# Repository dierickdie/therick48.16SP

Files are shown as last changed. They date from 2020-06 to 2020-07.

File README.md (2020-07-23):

# therick48.16SP
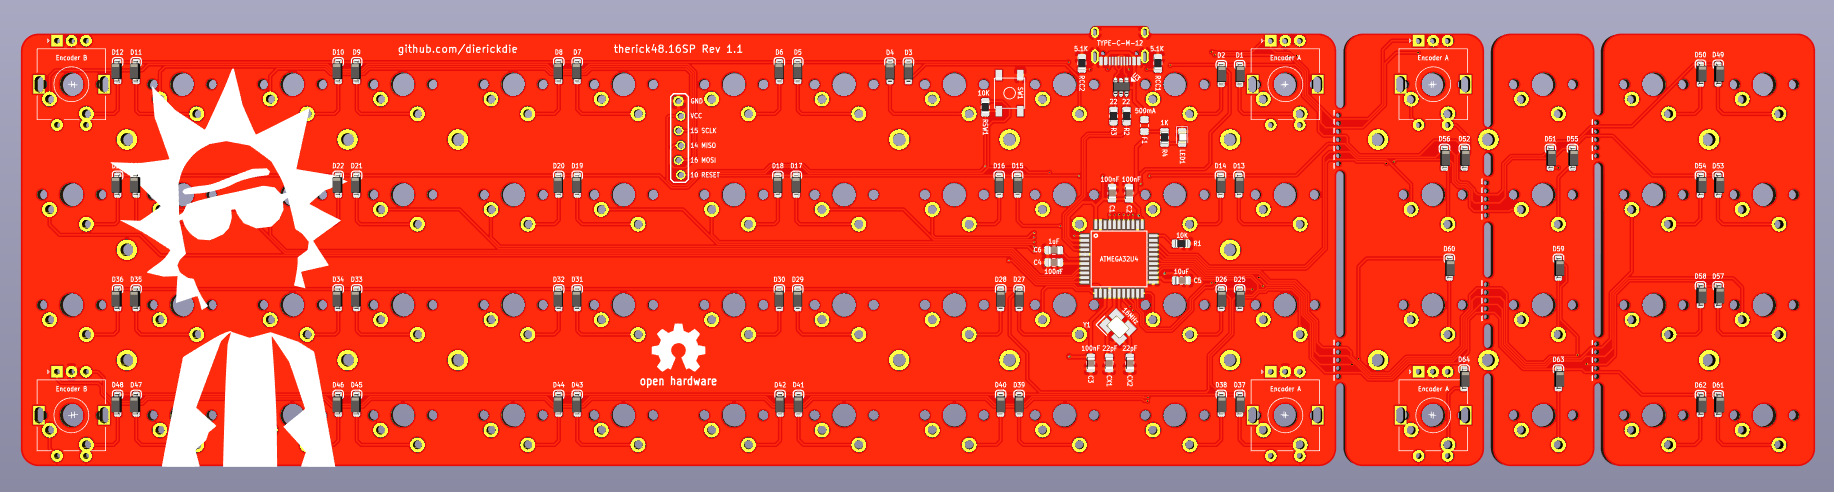
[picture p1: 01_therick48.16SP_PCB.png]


SP = Southpaw

A 4x12 + 4x4 (48.16) ortho keyboard with USB C, SMD components, and 19mm spacing.

This is essentially a dumbed down Planck clone plus a southpaw numpad. The numpad is able to be snapped off to have just a 4x12.

If you want a regular side numpad, look at the [therick48.16](https://github.com/dierickdie/therick64BA). It uses the same firmware.

**Note: firmware is the same as therick48.16**

Although everything should<sup>(tm)</sup> work as is, it hasn't been physically tested.

**USE AT YOUR OWN RISK!!!** I am not responsible for any dumb things you do, fry your computer, break anything, etc.

## FAQ:
#### Does it have MIT/2x2u/etc.? 
No. Grid for life

#### Does it have backlighting?
No

#### Does it have RGB?
No

#### Does it have a rotary encoder?
~No~ Yep! There are 8 (lol) choices for location. However, only support for 2. Left and right.

#### Does it have hotswap?
No

#### Does it have Alps support?
No

#### Choc support?
No

#### Will you add any of these?
No

#### Why not?
I don't wanna

#### Will it fit a Planck case?
Yes! In theory. If you break off the numpad. Hasn't been tested.

#### Why USB C?
That's a dumb question

#### Will you add micro/mini/any USB other than type C?
No

#### Why not?
USB C is the future. Until a new standard comes out

#### But I don't have any USB C cables.
Boo hoo. I suggest building one. Zap Cables is a good place to get parts

#### Why is it named therick?
It started in fall of 2005 when I was just a boy. I started a new job, and needed a login name. The manager wrote The Rick (my first name is Rick). It has stuck ever since. Thanks, Sam! 64 is for 64 keys. Hope that was obvious.

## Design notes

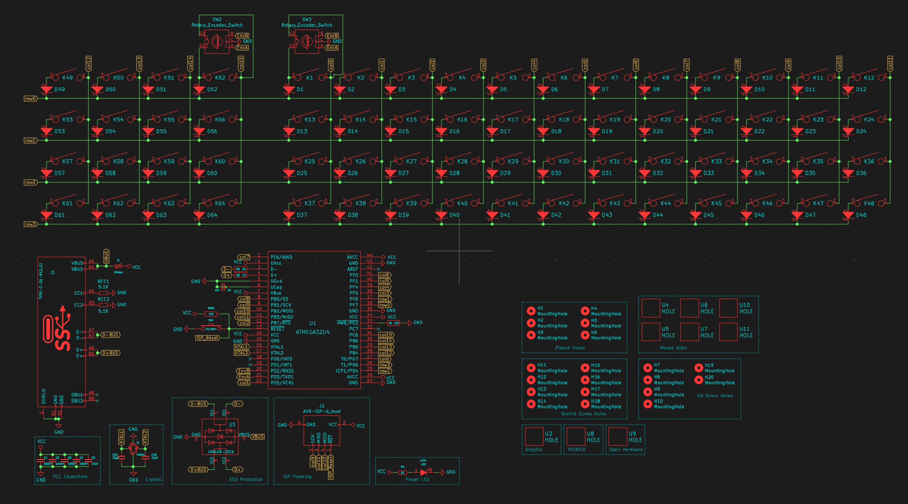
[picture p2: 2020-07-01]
04_Schematic.png

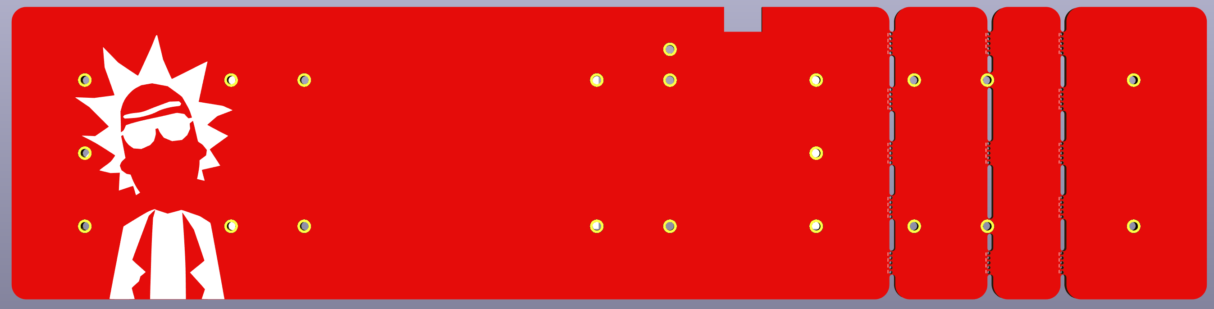
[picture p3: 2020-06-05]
03_therick48.16SP_bottom_plate.png

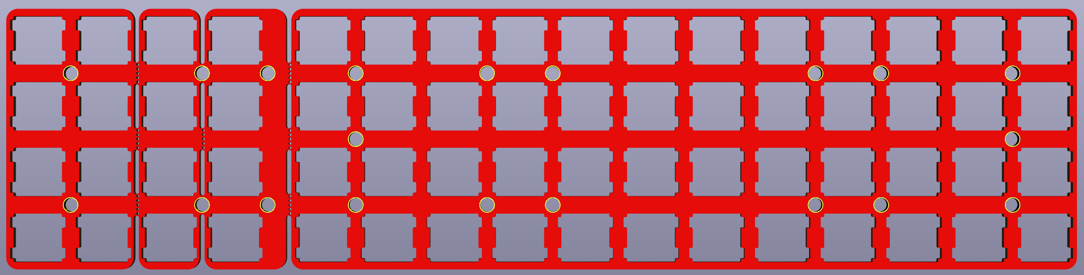
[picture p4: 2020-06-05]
02_therick48.16SP_top_plate.png

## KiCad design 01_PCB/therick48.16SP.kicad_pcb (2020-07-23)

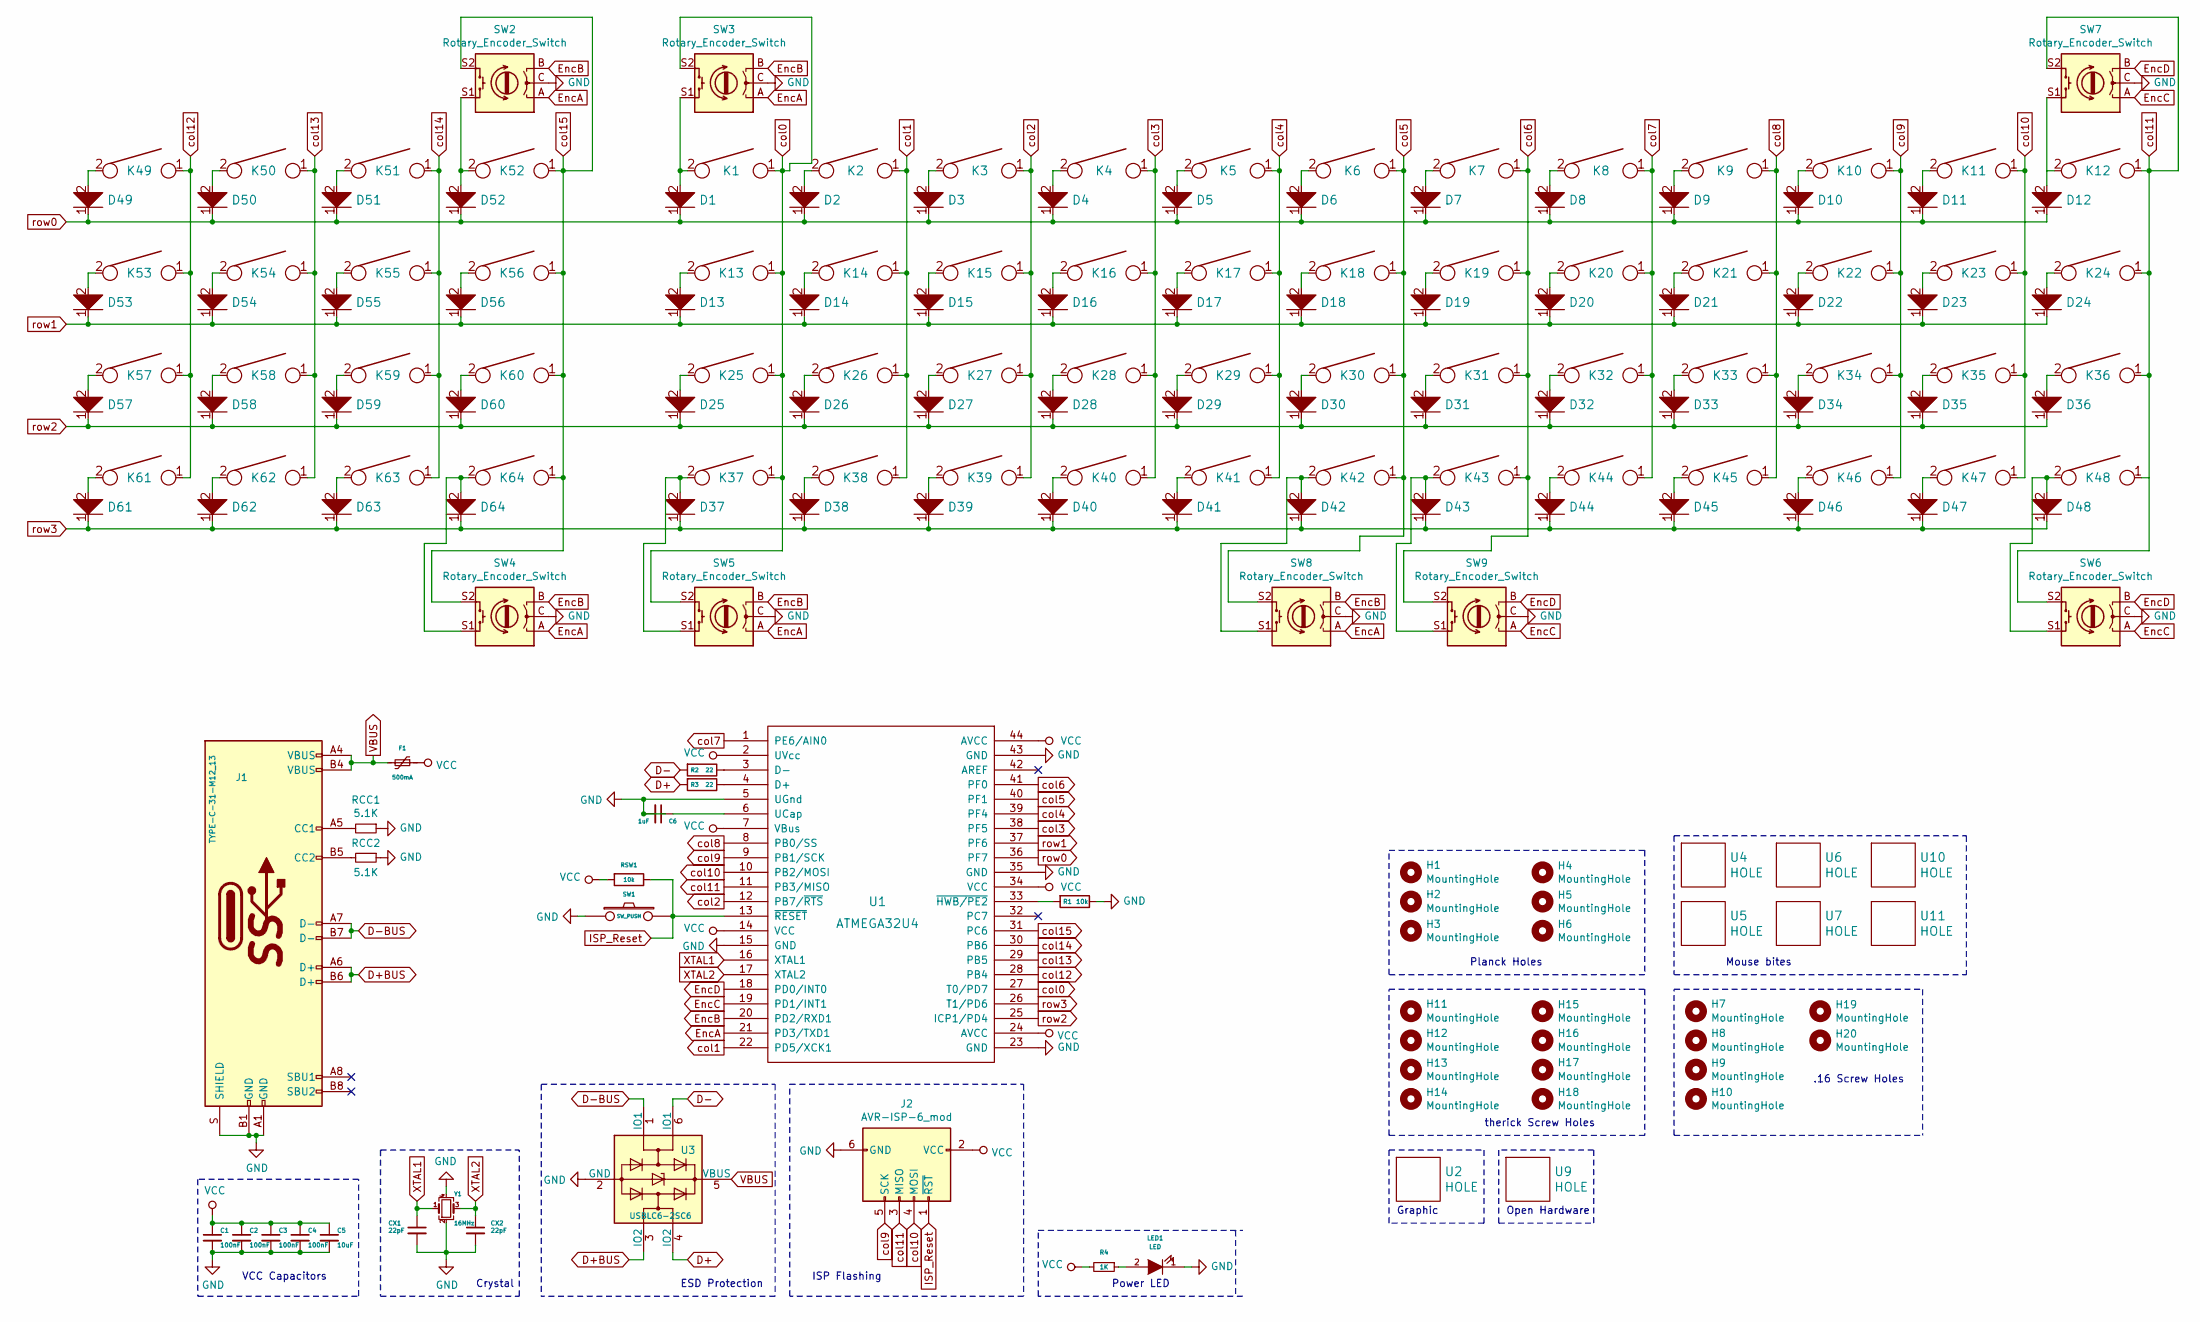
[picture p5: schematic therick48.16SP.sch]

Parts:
C1, C2, C3, C4: 100nF; C_0805_2012Metric_Pad1.15x1.40mm_HandSolder
C5: 10uF; C_0805_2012Metric_Pad1.15x1.40mm_HandSolder
C6: 1uF; C_0805_2012Metric_Pad1.15x1.40mm_HandSolder
CX1, CX2: 22pF; C_0805_2012Metric_Pad1.15x1.40mm_HandSolder
D1, D2, D3, D4, D5, D6, D7, D8, D9, D10, D11, D12, D13, D14, D15, D16, D17, D18, D19, D20, D21, D22, D23, D24, D25, D26, D27, D28, D29, D30, D31, D32, D33, D34, D35, D36, D37, D38, D39, D40, D41, D42, D43, D44, D45, D46, D47, D48, D49, D50, D51, D52, D53, D54, D55, D56, D57, D58, D59, D60, D61, D62, D63, D64: D; D_SOD-123_modified
F1: 500mA; Fuse_0805_2012Metric_Pad1.15x1.40mm_HandSolder
H1, H2, H3, H4, H5, H6, H7, H8, H9, H10, H11, H12, H13, H14, H15, H16, H17, H18, H19, H20: MountingHole; Generic-Mounthole
J1: TYPE-C-31-M12_13; TYPE-C-31-M-12
J2: AVR-ISP-6_mod; PIN_HEADER_1x6_OFFSET
K1, K2, K3, K4, K5, K6, K7, K8, K9, K10, K11, K12, K13, K14, K15, K16, K17, K18, K19, K20, K21, K22, K23, K24, K25, K26, K27, K28, K29, K30, K31, K32, K33, K34, K35, K36, K37, K38, K39, K40, K41, K42, K43, K44, K45, K46, K47, K48, K49, K50, K51, K52, K53, K54, K55, K56, K57, K58, K59, K60, K61, K62, K63, K64: KEYSW; MX100
LED1: LED; LED_0805_2012Metric_Pad1.15x1.40mm_HandSolder
R1: 10k; R_0805_2012Metric_Pad1.15x1.40mm_HandSolder
R2, R3: 22; R_0805_2012Metric_Pad1.15x1.40mm_HandSolder
R4: 1K; R_0805_2012Metric_Pad1.15x1.40mm_HandSolder
RCC1, RCC2: 5.1K; R_0805_2012Metric_Pad1.15x1.40mm_HandSolder
RSW1: 10k; R_0805_2012Metric_Pad1.15x1.40mm_HandSolder
SW1: SW_PUSH; SKQG-1155865
SW2, SW3, SW4, SW5, SW6, SW7, SW8, SW9: Rotary_Encoder_Switch; RotaryEncoder_EC11
U1: ATMEGA32U4; ATMEGA32U4-AU
U2: HOLE; rick_large
U3: USBLC6-2SC6; SOT-23-6
U4, U5, U6, U7, U10, U11: HOLE; MouseBite_IPC7351
U9: HOLE; OSHW-Logo2_14.6x12mm_SilkScreen
Y1: 16MHz; Crystal_SMD_3225-4Pin_3.2x2.5mm_HandSoldering

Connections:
D+: R3.2, U3.4 (IO2)
D+BUS: J1.A6 (D+), J1.B6 (D+), U3.3 (IO2)
D-: R2.2, U3.6 (IO1)
D-BUS: J1.A7 (D-), J1.B7 (D-), U3.1 (IO1)
EncA: SW2.A, SW3.A, SW4.A, SW5.A, SW8.A, U1.21 (PD3/TXD1)
EncB: SW2.B, SW3.B, SW4.B, SW5.B, SW8.B, U1.20 (PD2/RXD1)
EncC: SW6.A, SW7.A, SW9.A, U1.19 (PD1/INT1)
EncD: SW6.B, SW7.B, SW9.B, U1.18 (PD0/INT0)
GND: C1.2, C2.2, C3.2, C4.2, C5.2, C6.2, CX1.2, CX2.2, J1.A1 (GND), J1.B1 (GND), J1.S (SHIELD), J2.6 (GND), LED1.1 (K), R1.1, RCC1.1, RCC2.1, SW1.1, SW2.C, SW3.C, SW4.C, SW5.C, SW6.C, SW7.C, SW8.C, SW9.C, U1.5 (UGnd), U1.15 (GND), U1.23 (GND), U1.35 (GND), U1.43 (GND), U3.2 (GND), Y1.2, Y1.4
ISP_Reset: J2.1 (~RST), RSW1.1, SW1.2, U1.13 (~RESET)
unnamed: C6.1, U1.6 (UCap)
unnamed: D1.2, K1.2, SW3.S1
unnamed: D2.2, K2.2
unnamed: D3.2, K3.2
unnamed: D4.2, K4.2
unnamed: D5.2, K5.2
unnamed: D6.2, K6.2
unnamed: D7.2, K7.2
unnamed: D8.2, K8.2
unnamed: D9.2, K9.2
unnamed: D10.2, K10.2
unnamed: D11.2, K11.2
unnamed: D12.2, K12.2, SW7.S1
unnamed: D13.2, K13.2
unnamed: D14.2, K14.2
unnamed: D15.2, K15.2
unnamed: D16.2, K16.2
unnamed: D17.2, K17.2
unnamed: D18.2, K18.2
unnamed: D19.2, K19.2
unnamed: D20.2, K20.2
unnamed: D21.2, K21.2
unnamed: D22.2, K22.2
unnamed: D23.2, K23.2
unnamed: D24.2, K24.2
unnamed: D25.2, K25.2
unnamed: D26.2, K26.2
unnamed: D27.2, K27.2
unnamed: D28.2, K28.2
unnamed: D29.2, K29.2
unnamed: D30.2, K30.2
unnamed: D31.2, K31.2
unnamed: D32.2, K32.2
unnamed: D33.2, K33.2
unnamed: D34.2, K34.2
unnamed: D35.2, K35.2
unnamed: D36.2, K36.2
unnamed: D37.2, K37.2, SW5.S1
unnamed: D38.2, K38.2
unnamed: D39.2, K39.2
unnamed: D40.2, K40.2
unnamed: D41.2, K41.2
unnamed: D42.2, K42.2, SW8.S1
unnamed: D43.2, K43.2, SW9.S1
unnamed: D44.2, K44.2
unnamed: D45.2, K45.2
unnamed: D46.2, K46.2
unnamed: D47.2, K47.2
unnamed: D48.2, K48.2, SW6.S1
unnamed: D49.2, K49.2
unnamed: D50.2, K50.2
unnamed: D51.2, K51.2
unnamed: D52.2, K52.2, SW2.S1
unnamed: D53.2, K53.2
unnamed: D54.2, K54.2
unnamed: D55.2, K55.2
unnamed: D56.2, K56.2
unnamed: D57.2, K57.2
unnamed: D58.2, K58.2
unnamed: D59.2, K59.2
unnamed: D60.2, K60.2
unnamed: D61.2, K61.2
unnamed: D62.2, K62.2
unnamed: D63.2, K63.2
unnamed: D64.2, K64.2, SW4.S1
unnamed: J1.A5 (CC1), RCC1.2
unnamed: J1.B5 (CC2), RCC2.2
unnamed: LED1.2 (A), R4.1
unnamed: R1.2, U1.33 (~HWB/PE2)
unnamed: R2.1, U1.3 (D-)
unnamed: R3.1, U1.4 (D+)
VBUS: F1.2, J1.A4 (VBUS), J1.B4 (VBUS), U3.5 (VBUS)
VCC: C1.1, C2.1, C3.1, C4.1, C5.1, F1.1, J2.2 (VCC), R4.2, RSW1.2, U1.2 (UVcc), U1.7 (VBus), U1.14 (VCC), U1.24 (AVCC), U1.34 (VCC), U1.44 (AVCC)
XTAL1: CX1.1, U1.16 (XTAL1), Y1.1
XTAL2: CX2.1, U1.17 (XTAL2), Y1.3
col0: K1.1, K13.1, K25.1, K37.1, SW3.S2, SW5.S2, U1.27 (T0/PD7)
col1: K2.1, K14.1, K26.1, K38.1, U1.22 (PD5/XCK1)
col2: K3.1, K15.1, K27.1, K39.1, U1.12 (PB7/~RTS)
col3: K4.1, K16.1, K28.1, K40.1, U1.38 (PF5)
col4: K5.1, K17.1, K29.1, K41.1, U1.39 (PF4)
col5: K6.1, K18.1, K30.1, K42.1, SW8.S2, U1.40 (PF1)
col6: K7.1, K19.1, K31.1, K43.1, SW9.S2, U1.41 (PF0)
col7: K8.1, K20.1, K32.1, K44.1, U1.1 (PE6/AIN0)
col8: K9.1, K21.1, K33.1, K45.1, U1.8 (PB0/SS)
col9: J2.5 (SCK), K10.1, K22.1, K34.1, K46.1, U1.9 (PB1/SCK)
col10: J2.4 (MOSI), K11.1, K23.1, K35.1, K47.1, U1.10 (PB2/MOSI)
col11: J2.3 (MISO), K12.1, K24.1, K36.1, K48.1, SW6.S2, SW7.S2, U1.11 (PB3/MISO)
col12: K49.1, K53.1, K57.1, K61.1, U1.28 (PB4)
col13: K50.1, K54.1, K58.1, K62.1, U1.29 (PB5)
col14: K51.1, K55.1, K59.1, K63.1, U1.30 (PB6)
col15: K52.1, K56.1, K60.1, K64.1, SW2.S2, SW4.S2, U1.31 (PC6)
row0: D1.1, D2.1, D3.1, D4.1, D5.1, D6.1, D7.1, D8.1, D9.1, D10.1, D11.1, D12.1, D49.1, D50.1, D51.1, D52.1, U1.36 (PF7)
row1: D13.1, D14.1, D15.1, D16.1, D17.1, D18.1, D19.1, D20.1, D21.1, D22.1, D23.1, D24.1, D53.1, D54.1, D55.1, D56.1, U1.37 (PF6)
row2: D25.1, D26.1, D27.1, D28.1, D29.1, D30.1, D31.1, D32.1, D33.1, D34.1, D35.1, D36.1, D57.1, D58.1, D59.1, D60.1, U1.25 (ICP1/PD4)
row3: D37.1, D38.1, D39.1, D40.1, D41.1, D42.1, D43.1, D44.1, D45.1, D46.1, D47.1, D48.1, D61.1, D62.1, D63.1, D64.1, U1.26 (T1/PD6)

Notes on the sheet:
VCC Capacitors
Planck Holes
Graphic
Crystal
ESD Protection
ISP Flashing
Mouse bites
therick Screw Holes
.16 Screw Holes
Power LED
Open Hardware

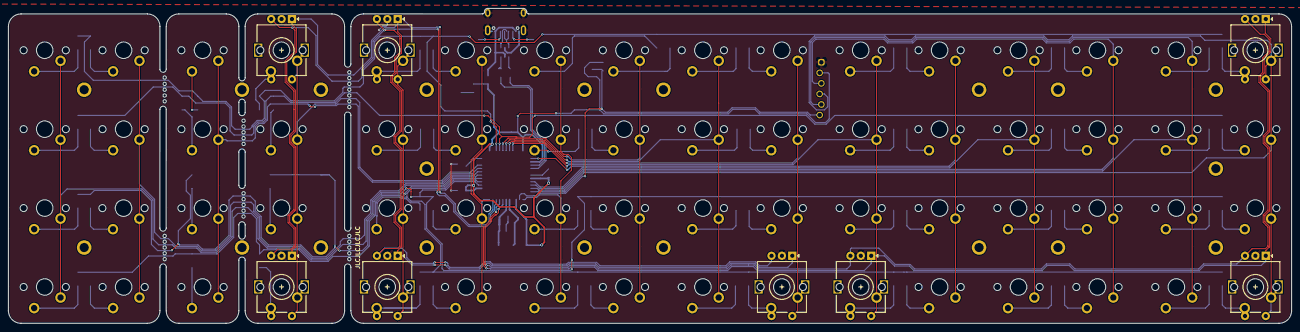
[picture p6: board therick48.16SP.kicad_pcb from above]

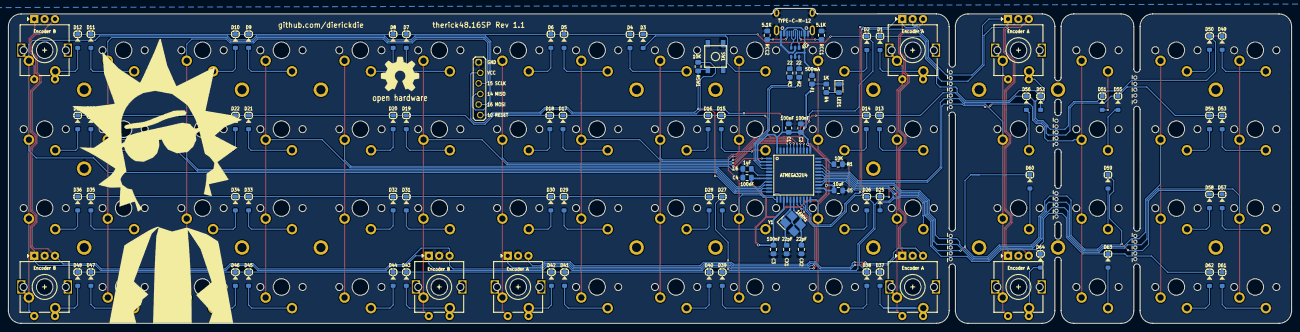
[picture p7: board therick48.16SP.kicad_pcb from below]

Board: 2 copper layers, 308.9 x 75.8 mm, 187 parts (89 on the bottom side), 105 nets.

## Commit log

2020-02-08 Update some routing
    [therick64BASP.kicad_pcb, therick64BASP_bottom_plate.kicad_pcb, therick64BASP_bottom_plate.sch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]
2020-02-08 Align Switches
    [therick64BASP.kicad_pcb]
2020-02-23 Changed pins to make routing cleaner
    [therick64BASP-B_Cu.gbr, therick64BASP-B_Mask.gbr, therick64BASP-B_Paste.gbr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]
2020-05-15 Remapped ISP Flash, added mounting holes
    [therick64BASP-B_Cu.gbr, therick64BASP-B_Mask.gbr, therick64BASP-B_Paste.gbr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]
2020-05-16 Add reset hole
    [therick64BASP_bottom_plate-B_Cu.gbr, therick64BASP_bottom_plate-B_Mask.gbr, therick64BASP_bottom_plate-B_Paste.gbr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]
2020-05-16 Update schematic
    [therick64BASP.sch]
2020-05-19 Added mounting holes
    [therick64BASP-B_Cu.gbr, therick64BASP-B_Mask.gbr, therick64BASP-B_Paste.gbr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]
2020-05-23 Rename from therick64 to therick48.16
    [therick48.16BASP.kicad_pcb, therick48.16BASP.sch, therick48.16BASP_bottom_plate.kicad_pcb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]
2020-05-23 Rename files
    [therick48.16SP-B_Cu.gbr, therick48.16SP-B_Mask.gbr, therick48.16SP-B_Paste.gbr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]
2020-05-23 Changed gap between 4X12 and 4X4 to .25 inches
    [therick48.16SP.kicad_pcb, therick48.16SP_bottom_plate.kicad_pcb, therick48.16SP_top_plate.kicad_pcb]
2020-05-23 Changed a trace
    [therick48.16SP-B_Cu.gbr, therick48.16SP-B_Mask.gbr, therick48.16SP-B_Paste.gbr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]
2020-05-24 48+16SP to 48.16SP
    [therick48.16SP-B_Cu.gbr, therick48.16SP-B_Mask.gbr, therick48.16SP-B_Paste.gbr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]
2020-05-24 Change 48+16SP to 48.16SP
    [therick48.16SP-B_Cu.gbr, therick48.16SP-B_Mask.gbr, therick48.16SP-B_Paste.gbr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]
2020-05-25 Add power LED
    [therick48.16SP.kicad_pcb, therick48.16SP.sch]
2020-05-30 New Gerber files
    [therick48.16SP-B_Cu.gbr, therick48.16SP-B_Mask.gbr, therick48.16SP-B_Paste.gbr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]
2020-06-03 Made 2 columns able to be broken away
    [therick48.16SP-B_Cu.gbr, therick48.16SP-B_Mask.gbr, therick48.16SP-B_Paste.gbr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]
2020-06-05 Added breakaway section, added rotary encoder support
    [therick48.16SP.kicad_pcb, therick48.16SP.sch, therick48.16SP_bottom_plate.kicad_pcb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]
2020-06-05 Update Gerbers
    [therick48.16SP-B_Cu.gbr, therick48.16SP-B_Mask.gbr, therick48.16SP-B_Paste.gbr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]
2020-06-06 New gerber
    [therick48.16SP-B_Cu.gbl, therick48.16SP-B_Mask.gbr, therick48.16SP-B_Mask.gbs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]
2020-06-06 Create Rev 1.0
    [therick48.16SP-B_Cu.gbl, therick48.16SP-B_Mask.gbs, therick48.16SP-B_Paste.gbp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]
2020-06-21 Small aesthetic tweaks
    [therick48.16SP-B_Cu.gbl, therick48.16SP-B_Mask.gbs, therick48.16SP-B_Paste.gbp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]
2020-07-01 Added encoder
    [therick48.16SP-B_Cu.gbl, therick48.16SP-B_Mask.gbs, therick48.16SP-B_Paste.gbp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]
